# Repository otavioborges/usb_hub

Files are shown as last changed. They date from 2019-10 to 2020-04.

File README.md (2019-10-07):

# Active USB Hub - Ello Govnor

This project comprises shcematics and PCB for a active USB Hub. Using a USB2514B for USB switching and a LPC11U35/401 for host and power control.

## Using the Project

Published under GNU v3 license. Project created on KiCAD v5.0.2. Using default software libraries

## Handbonning capabilities

The project includes three different types of handbonning. **USE WITH CAUTION**.

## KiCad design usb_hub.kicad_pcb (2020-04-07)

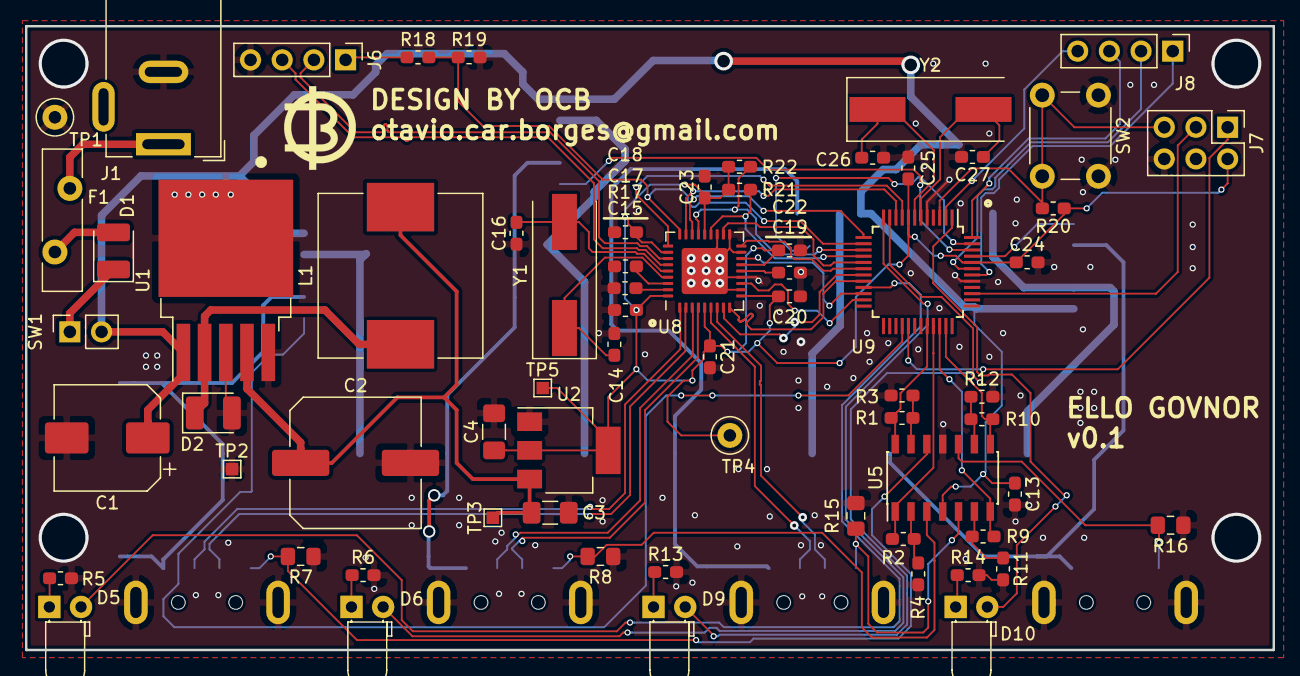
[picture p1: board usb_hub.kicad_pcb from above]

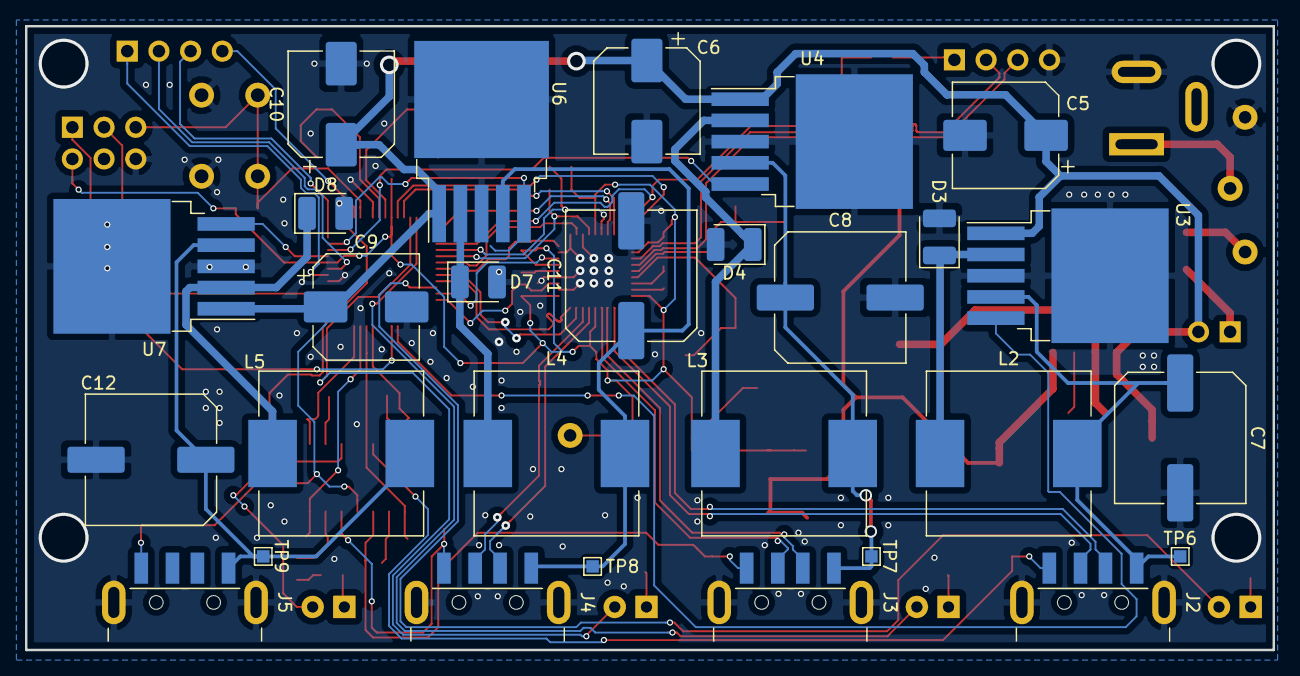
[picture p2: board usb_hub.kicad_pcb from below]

Board: 2 copper layers, 100.0 x 50.0 mm, 95 parts (28 on the bottom side), 75 nets.

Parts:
C1, C5, C6, C9, C10: 470uF; CP_Elec_8x10
C2, C7, C8, C11, C12: 220uF; C_Elec_10x10.2
C3, C4: 10uF; C_1206_3216Metric_Pad1.42x1.75mm_HandSolder
C13, C15, C17, C18, C19, C20, C21, C22, C23, C24, C25: 0.1uF; C_0603_1608Metric_Pad1.05x0.95mm_HandSolder
C14, C16, C26, C27: 39pF; C_0603_1608Metric_Pad1.05x0.95mm_HandSolder
D1, D2, D3, D4, D7, D8: VSSAF5L45; D_1210_3225Metric_Pad1.42x2.65mm_HandSolder
D5, D6, D9, D10: LED; LED_D3.0mm_Horizontal_O1.27mm_Z2.0mm
F1: 5A/16V; Fuse_Bourns_MF-RHT500
J1: Barrel_Jack_Switch; BarrelJack_Wuerth_6941xx301002
J2, J3, J4, J5: USB_A; USB_A_CNCTech_1001-011-01101_Horizontal
J6, J8: Conn_01x04; PinHeader_1x04_P2.54mm_Vertical
J7: Conn_02x03_Odd_Even; PinHeader_2x03_P2.54mm_Vertical
L1, L2, L3, L4, L5: 33uH; L_Neosid_SM-NE127_HandSoldering
R1, R2, R9, R10: 99k; R_0603_1608Metric_Pad1.05x0.95mm_HandSolder
R3, R4, R11, R12: 1k; R_0603_1608Metric_Pad1.05x0.95mm_HandSolder
R5, R6, R13, R14: 39; R_0603_1608Metric_Pad1.05x0.95mm_HandSolder
R7, R8, R15, R16: 10m; R_0805_2012Metric_Pad1.15x1.40mm_HandSolder
R17: 12K; R_0603_1608Metric_Pad1.05x0.95mm_HandSolder
R18: 5k; R_0603_1608Metric_Pad1.05x0.95mm_HandSolder
R19, R20, R21, R22: 10K; R_0603_1608Metric_Pad1.05x0.95mm_HandSolder
SW1: SW_DIP_x01; PinSocket_1x02_P2.54mm_Vertical
SW2: SW_Push; SW_PUSH_6mm
TP1, TP4: TestPoint_Alt; TestPoint_Loop_D1.80mm_Drill1.0mm_Beaded
TP2: TestPoint; TestPoint_Pad_1.0x1.0mm
TP3, TP5, TP6, TP7, TP8, TP9: Test_Point; TestPoint_Pad_1.0x1.0mm
U1, U3, U4, U6, U7: AP1501A-50K5G-13; TO-263-5_TabPin3
U2: LM1117-3.3; SOT-223-3_TabPin2
U5: LM324; SOIC-14_3.9x8.7mm_P1.27mm
U8: USB2514B_Bi; QFN-36-1EP_6x6mm_P0.5mm_EP3.7x3.7mm
U9: LPC11U35FBD48-401; TQFP-48_7x7mm_P0.5mm
Y1, Y2: 24MHz; Crystal_SMD_HC49-SD

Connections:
+3V3: C4.1, C15.1, C18.1, C20.1, C21.1, C22.1, C23.1, C24.1, C25.1, J7.2, R20.1, R21.1, R22.1, TP4.1, TP5.1, U2.2, U8.5, U8.10, U8.15, U8.23, U8.29, U8.36, U9.8, U9.44
+5V: C2.1, C3.1, L1.2, TP3.1, U1.4, U2.3
/FEED: F1.2, J1.1
/FUSED: D1.2, F1.1
/Host & Controller/HUB_HS: U8.25, U9.13
/Host & Controller/HUB_PWR1: U8.12, U9.23
/Host & Controller/HUB_PWR2: U8.16, U9.22
/Host & Controller/HUB_PWR3: U8.18, U9.18
/Host & Controller/HUB_PWR4: U8.20, U9.17
/Host & Controller/HUB_RESET: U8.26, U9.10
/Host & Controller/HUB_SUSP: U8.28, U9.9
/Host & Controller/MAIN_D+: J6.3, U8.31
/Host & Controller/MAIN_D-: J6.2, U8.30
/Host & Controller/MCU_SCL: R22.2, U8.24, U9.15
/Host & Controller/MCU_SDA: R21.2, U8.22, U9.16
/Host & Controller/MCU_VBUS_DET: R18.2, R19.1, U8.27, U9.14
/Host & Controller/RESET: J7.5, R20.2, SW2.2, U9.3
/Host & Controller/SPARE_1: J8.4, U9.2
/Host & Controller/SPARE_2: J8.3, U9.48
/Host & Controller/SPARE_3: J8.2, U9.43
/Host & Controller/SPARE_4: J8.1, U9.42
/Host & Controller/SWCLK: J7.1, U9.29
/Host & Controller/SWDIO: J7.3, U9.39
/SWITCH: D1.1, SW1.1
/USB Ports/USB1_5V: C7.1, J2.1, L2.2, TP6.1, U3.4
/USB Ports/USB2_5V: C8.1, J3.1, L3.2, TP7.1, U4.4
/USB Ports/USB3_5V: C11.1, J4.1, L4.2, TP8.1, U6.4
/USB Ports/USB4_5V: C12.1, J5.1, L5.2, TP9.1, U7.4
GND: C1.2, C2.2, C3.2, C4.2, C5.2, C6.2, C7.2, C8.2, C9.2, C10.2, C11.2, C12.2, C13.2, C14.2, C15.2, C16.2, C17.2, C18.2, C19.2, C20.2, C21.2, C22.2, C23.2, C24.2, C25.2, C26.2, C27.2, D2.2, D3.2, D4.2, D7.2, D8.2, J1.2, J2.5, J3.5, J4.5, J5.5, J6.4, J7.6, R3.2, R4.2, R5.2, R6.2, R7.1, R8.1, R11.2, R12.2, R13.2, R14.2, R15.1, R16.1, R17.2, R19.2, SW2.1, TP1.1, TP2.1, U1.3, U1.5, U2.1, U3.3, U4.3, U5.11, U6.3, U7.3, U8.11, U8.13, U8.17, U8.19, U8.21, U8.37, U9.5, U9.41
unnamed: C14.1, U8.33, Y1.1
unnamed: C16.1, U8.32, Y1.2
unnamed: C17.1, U8.34
unnamed: C19.1, U8.14
unnamed: C26.1, U9.7, Y2.1
unnamed: C27.1, U9.6, Y2.2
unnamed: D2.1, L1.1, U1.2
unnamed: D3.1, L2.1, U3.2
unnamed: D4.1, L3.1, U4.2
unnamed: D5.1, R5.1
unnamed: D6.1, R6.1
unnamed: D7.1, L4.1, U6.2
unnamed: D8.1, L5.1, U7.2
unnamed: D9.1, R13.1
unnamed: D10.1, R14.1
unnamed: J2.4, R7.2, U5.12
unnamed: J3.4, R8.2, U5.3
unnamed: J4.4, R15.2, U5.5
unnamed: J5.4, R16.2, U5.10
unnamed: J6.1, R18.1
unnamed: R1.2, R3.1, U5.13
unnamed: R2.2, R4.1, U5.2
unnamed: R10.2, R12.1, U5.9
unnamed: R9.2, R11.1, U5.6
unnamed: R17.1, U8.35
USB1_CHG: U3.5, U9.28
USB1_CUR: R1.1, U5.14, U9.32
USB1_D+: J2.3, U8.2
USB1_D-: J2.2, U8.1
USB1_ONLED: D5.2, U9.21
USB2_CHG: U4.5, U9.46
USB2_CUR: R2.1, U5.1, U9.33
USB2_D+: J3.3, U8.4
USB2_D-: J3.2, U8.3
USB2_ONLED: D6.2, U9.12
USB3_CHG: U6.5, U9.47
USB3_CUR: R9.1, U5.7, U9.34
USB3_D+: J4.3, U8.7
USB3_D-: J4.2, U8.6
USB3_ONLED: D9.2, U9.11
USB4_CHG: U7.5, U9.45
USB4_CUR: R10.1, U5.8, U9.35
USB4_ONLED: D10.2, U9.1
USB_MCU+: U8.9, U9.20
USB_MCU-: U8.8, U9.19
VBUS: C1.1, C5.1, C6.1, C9.1, C10.1, C13.1, SW1.2, U1.1, U3.1, U4.1, U5.4, U6.1, U7.1

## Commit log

2019-10-07 Initial project files commit. Ready for v0.1
    [host_controller.sch, usb_hub.kicad_pcb, usb_hub.sch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]
2020-04-07 Fixing USB conn. gender and others: * 5V supply is simplified in one controller (55W); * Each USB port has it's on Current/Mode controller;
    [host_controller.sch, usb_hub.kicad_pcb, usb_hub.sch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]
